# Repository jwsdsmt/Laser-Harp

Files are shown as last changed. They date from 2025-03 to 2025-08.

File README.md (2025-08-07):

# Laser-Harp
Pluck a laser beam to play a harpstring!

Well, not really. For one, it's a laser: you can't pluck it. For another, you don't pluck it, because the note sustains for as long as the beam is broken. For a third, plucking the laser doesn't play a note. Instead, the project uses time of flight sensors to determine when a hand is plucking the laser beam, and then plays a note.

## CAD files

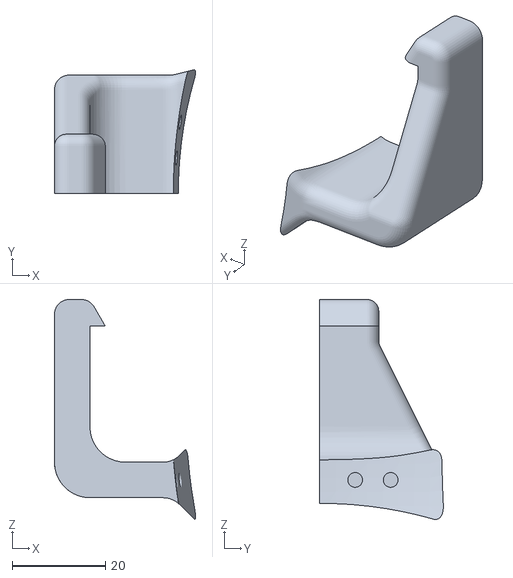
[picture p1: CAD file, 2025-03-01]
CAD Files/Lazer Harp opposite side rear mount.STL
30.3 x 26.5 x 47.2

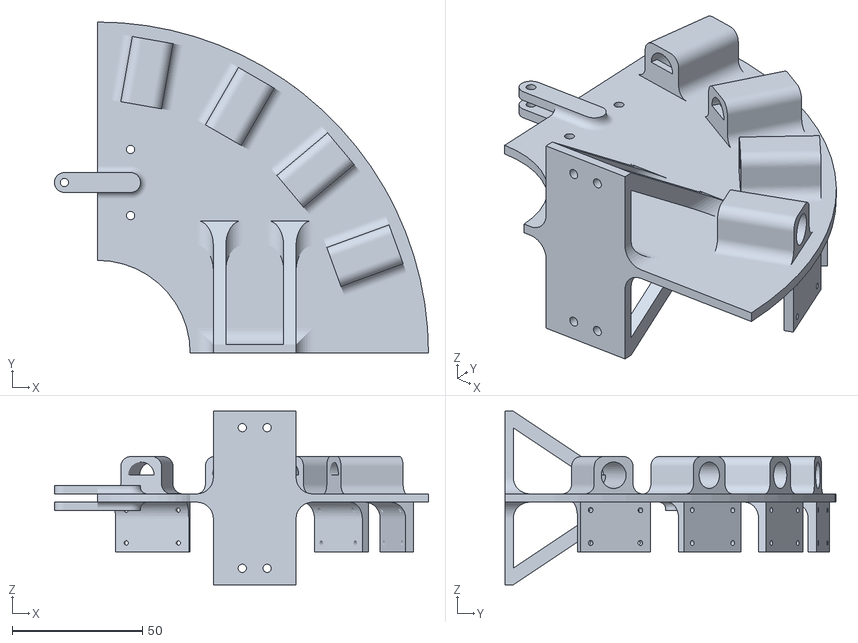
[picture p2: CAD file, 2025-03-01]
CAD Files/Lazer Harp Right Sensor Mount.STL
143.5 x 127.0 x 66.7

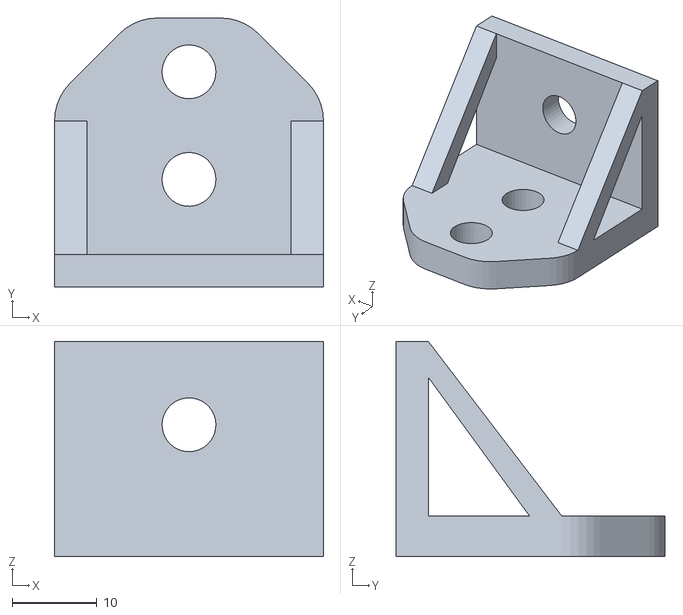
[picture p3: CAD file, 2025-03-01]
CAD Files/Lazer Harp Arch Tabs.STL
31.8 x 31.8 x 25.4

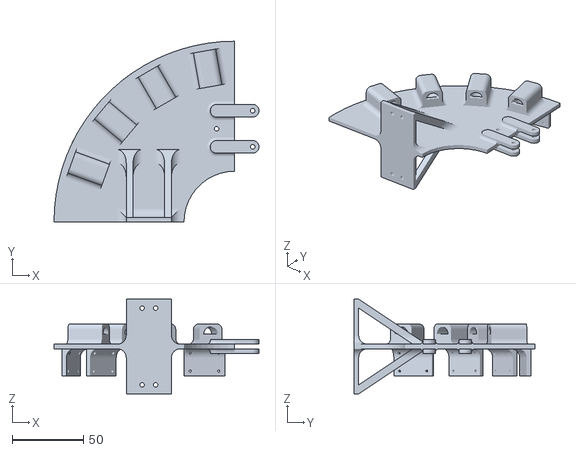
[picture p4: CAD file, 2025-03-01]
CAD Files/Lazer Harp Left Sensor Mount.STL
144.1 x 127.0 x 66.7

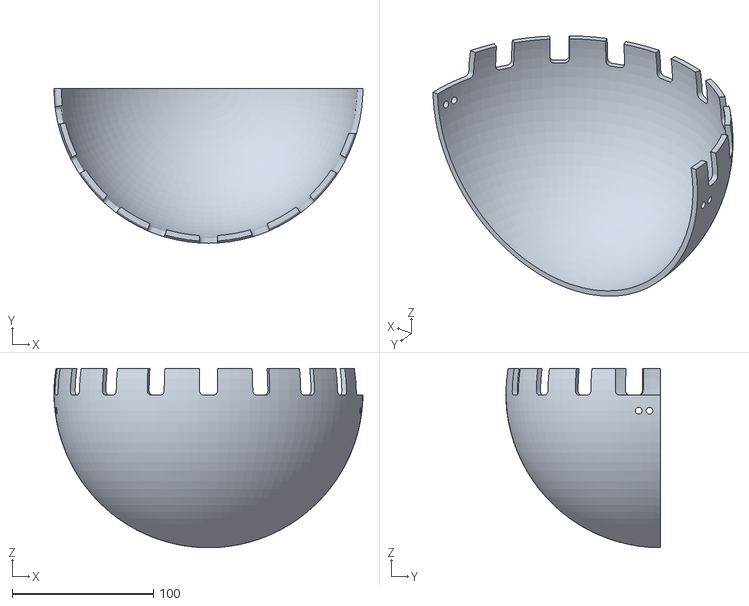
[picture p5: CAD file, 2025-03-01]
CAD Files/Lazer Harp Rear Cover.STL
218.7 x 109.4 x 127.0

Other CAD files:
CAD Files/Lazer Harp Rear Cover Mount near side.STL

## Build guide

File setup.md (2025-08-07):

# Setting Up the Device

This document assumes you have already correctly fabricated and assembled the laser harp.

This device uses CircuitPython, a variant of MicroPython maintained by Adafruit, which runs on their boards.

The circuitpy directory contains all the code you need to get the device working, written for CircuitPython 9.x.
Install CircuitPython 9.x on your Adafruit Feather RP2040, then copy code.py and the lib folder from this project to the CIRCUITPY drive of the board.
If you are using a different version of CircuitPython, download the official CircuitPython bundle for that version, and check to make sure all the libraries this project uses are available.
Then, replace the modules contained in the lib folder with those compiled for your version of CircuitPython, obtained from the bundle.

The code.py file should never need to be modified, because the device is self calibrating.
Unless a newer version of the libraries or CircuitPython introduce breaking changes, you should be good to go.

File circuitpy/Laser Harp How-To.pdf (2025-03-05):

Laser Harp info
Helpful links:
1) hps://learn.adafruit.com/adafruit-feather-m4-express-atsamd51/overview
2) hps://nickfever.com/music/midi-cc-list
3) hps://learn.adafruit.com/adafruit-music-maker-featherwing
4) hps://learn.adafruit.com/midi-laser-harp-me-of-flight-sensors/overview
Important Warnings: DO NOT TOUCH the TOF sensors. They are very sensive, and a touch from your finger can mess the sensor up temporarily or break them. The blue and yellow wires are not secured super well in their manufactured connectors, so be careful while handling. There is a reset buon on each of the Adafruit circuit boards, and if this is pressed, circuitpython will have to be reinstalled on the boards, and your code WILL be lost. I have saved a copy on my computer, and I advise you do the same as you edit. It is unlikely, since the buon must be pressed twice within a given amount of me, but it can be accidentally pressed. Avoid touching EITHER buon, since they both will wipe the board.
For assembly, see link 4. Power is sent from TOF sensor 0 through TOF 7. SDA and SCL (blue and yellow wires) informaon is sent from each sensor to the blue accumulator board. These are condensed into one stream of data which is sent to the doubler, the larger board underneath the two processing boards. The laser switch, the toggle switch embedded in the 3-D printed manifold, is between the 3.3V pin on the M4 express and the lasers posive terminals. It is useful during setup, but it maers less during actual use. The toggle switch connected only to the doubler is used to toggle between modes. If the switch is on, it plays a modulang mode. When your hand is brought back and forth, you will increase and decrease the volume of the note. When the switch is off, a two-step mode is turned on. When you have your hand low, it’ll play one note, while if your hand is higher, it will play the same note one octave higher. The lasers are not responsible for anything in this setup besides the visual.
These boards are designed to be easy to program, and while it is true, they have their quirks. They run on Circutpython, a division of python which is designed to run Adafruit’s circuit boards. Some of the usual python modules will no longer be accessible, so somemes you must do things the ‘brute force’ way with your code.
As seen in the code, this process works by cycling through each TOF sensor, checking to see how far the distance they are reading is, and consequently playing a note, or turning a note off. The M4 express (link 1) has all the useful code on it, while the music maker featherwing (link 3) synthesizes the notes. For the featherwing to process the midi notes, the midi jumper on the underside MUST be soldered. To access the code, download the MU python editor. For code to compile and run, simply save the sketch you’re working on, and it will automacally play, so long as the name of your file is code.py. The M4 express is designed to run only on files with that name. If you do some digging in link 1, you will see there are 3 other names, but the process is sll the same. The board will only run one file, and it’ll run the first file it finds with the name code.py. (If you have other python apps on your PC, they will not work if you have a file name of code.py on your PC, heads up) In the code, more than once you will see an instance of “midi.send(ControlChange…)”. These control changes can be used to alter the notes, and that is how I modulate the notes while the mode switch is on. More info in link 2.

Warning - the code downloaded off the Adafruit laser harp tutorial isn’t perfect, and in fact, the sensors give rather noisy data. To produce sound, I had to alter the code, but it would chirp from all different notes. Therefore, most of my me coding was spent finding a way to successfully clean up the data. While it isn’t perfect yet, it is prey good.
Common code errors: No I2C address at 0x29… This means that one of the sensors is not communicang. Find the line in the code, comment out the sensor, and remove the sensor name from the array of sensors directly below. Scroll down to the for loops and adjust the range to whatever quanty of sensors is sll ranging. No SDA/SCL pull up… unplug the board, wait, and replug. If it sll doesn’t work, if you’ve removed the boards from the doubler and reinstalled them, you may have switched them. Switch them back and try again. Code stops running… No maer what failed, if it was a one-off, you can unplug the board, and re-plug to restart the code.
Areas for improvement: 1) Lessening the ‘lag’ between when your hand interrupts the laser, and when the note is played. This delay is largely due to the debouncer. If there was another, faster way to debounce the data, that’d be great, as right now I’m using both the values in a list, and the std deviaon from that list to ensure the values that we want are playing. 2) While in two-note mode, the notes will not transfer between high and low if your hand moves from one to the other while the note is ‘on’. I tried this but was unable to make the switchover happen.

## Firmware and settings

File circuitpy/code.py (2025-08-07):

#imports
import time
import board
import busio
import adafruit_vl53l4cd
import adafruit_tca9548a
import adafruit_midi
from adafruit_midi.note_off import NoteOff
from adafruit_midi.note_on import NoteOn
from adafruit_midi.program_change import ProgramChange
from adafruit_midi.control_change import ControlChange

OFF = 0
LOW = 1
HIGH = 2

def map_scale(val, min1, max1, min2, max2):
    return min(max(val - min1, 0) / (max1 - min1), 1) * (max2 - min2) + min2
    
#  height cutoff for tof sensors in cm
#  adjust depending on the height of your ceiling/performance area
flight_height = 10

i2c = board.I2C()
tca = adafruit_tca9548a.TCA9548A(i2c)

flights = [None] * len(tca)
keystate = [OFF] * len(tca)
flight_heights = [flight_height] * len(tca)

for i in range(len(tca)):
    flights[i] = adafruit_vl53l4cd.VL53L4CD(tca[len(tca) - i - 1])
    flights[i].inter_measurement = 50
    flights[i].timing_budget = 10
    flights[i].start_ranging()

#  midi uart setup for music maker featherwing - baudrate should stay at 31250, otherwise MIDI will no longer communicate
uart = busio.UART(board.TX, board.RX, baudrate=31250)

midi_in_channel = 1
midi_out_channel = 1

#  midi setup
#  UART is setup as the input
midi = adafruit_midi.MIDI(
    midi_in=uart,
    midi_out=uart,
    in_channel=(midi_in_channel - 1),
    out_channel=(midi_out_channel - 1),
    debug=False,
)

#sets midi notes for the different modes
low_notes = [48, 50, 52, 53, 55, 57, 59, 60]
high_notes = [60, 62, 64, 65, 67, 69, 71, 72]

midi.send(ControlChange(121, 0))
midi.send(ProgramChange(23))
program = 0

previous_time = time.monotonic()
current_time = time.monotonic()
frequency = 100
timestep = 1 / frequency

while True:
    current_time = time.monotonic()
    if current_time < previous_time + timestep:
        continue
    previous_time = current_time

    for i in range(len(flights)):
        if not flights[i].data_ready:
            pass
        flights[i].clear_interrupt()
        distance = flights[i].distance
        flight_heights[i] = flight_heights[i] * 0.999 + distance * 0.001

        current_state = OFF
        if distance < flight_heights[i] * 5/8:
            current_state = LOW
        
        if current_state != keystate[i]:
            keystate[i] = current_state
            if current_state == OFF:
                midi.send(NoteOff(low_notes[i]))
            if current_state == LOW:
                midi.send(NoteOn(low_notes[i]))

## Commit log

2025-03-01 Added Cad models
    [Lazer Harp Arch Tabs.STL, Lazer Harp Left Sensor Mount.STL, Lazer Harp Rear Cover Mount near side.STL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]
2025-08-07 Fixed Code, removed unused files
    [code.py]
